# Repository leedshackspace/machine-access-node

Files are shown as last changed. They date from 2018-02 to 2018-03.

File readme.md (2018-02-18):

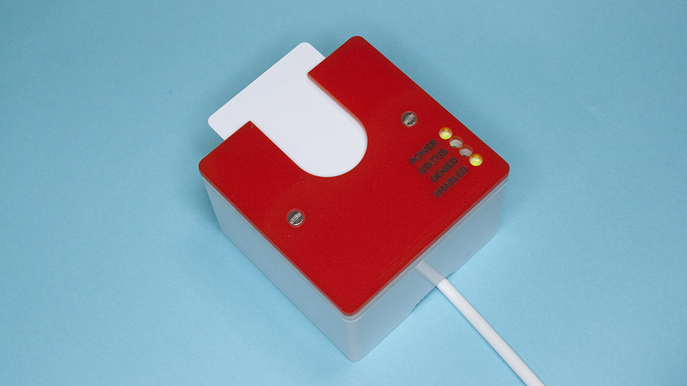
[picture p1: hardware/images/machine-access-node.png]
Machine Access Node


# Machine Node (WiFi)

Hardware and firmware to provide restricted access to dangerous and delicate
tools. Built around an ESP8266 (WeMos D1 mini) and RFID-RC522 breakout.

Designed to be easy to build for all levels of experience - simply order the PCB
from DirtyPCBs or OSHPark and solder the through hole parts to the board.
Software builds through the Arduino environment and will flash directly to the
WeMos board over USB.

## Hardware

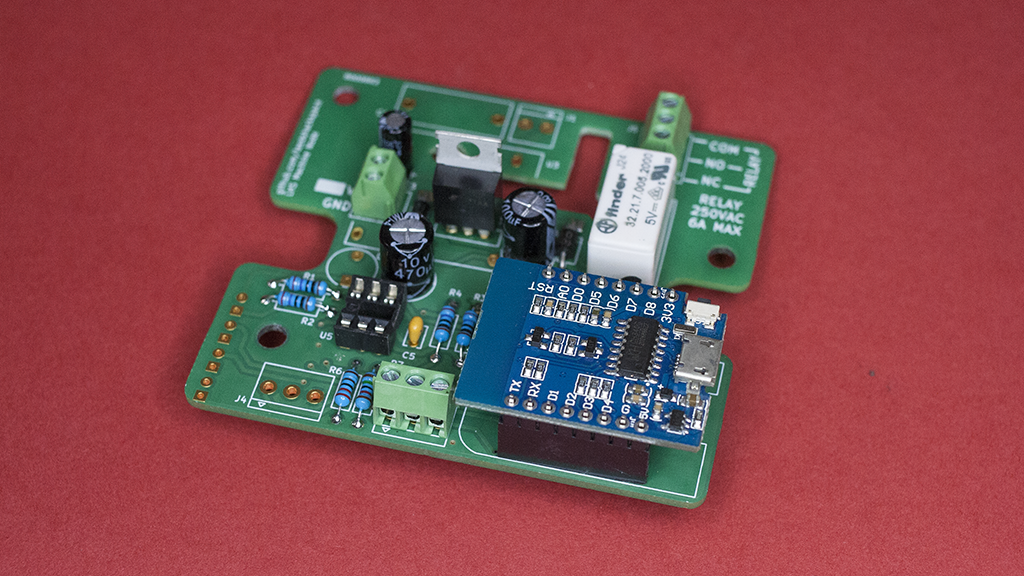
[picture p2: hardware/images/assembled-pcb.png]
Populated PCB


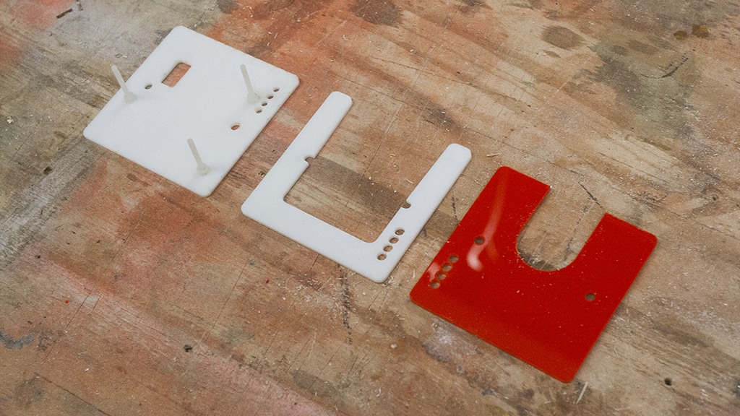
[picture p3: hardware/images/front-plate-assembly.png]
Faceplates for assembly


To build a machine node you simply need to acquire a PCB - gerbers are available
in the hardware folder - and order the parts listed in the BOM.

[Schematic](hardware/images/schematic-rev1.png).

### Power Supply Options

There are three power supply options.

* **12 V DC Power**  
  This is the recommended option. Populate the 12 V DC section of the schematic, and also `C4` if you wish.
* **5 V DC Power** (Untested)  
  Populate the 12 V DC section of the schematic, and do not fit `U2` or `D2`. Use a jumper wire to bridge `D2` and connect the solder jumper `JP1`.  
  There is no polarity protection in this configuration.
* **240 AC Mains Power** (Untested)  
  Populate the 240 V AC section of the schematic. There is a PTC fuse inside the AC-DC power supply `U3` but there should be external fusing as well to protect small gauge cabling coming into the terminals.

### Relay Contacts

The relay is rated for 250 V, 6 A max. If you are switching heavy loads it is recommended that you use this to trip an external contactor.

### Latch Mode

The default state is "Present" mode, that is, the output will turn on when the card
is present and it will turn off when it is removed. An as yet untested mode allows the
node to read a card once and then keep the output enabled until an external signal is
received.

Feel free to test this mode out, you can modify settings in `settings.h`. Remember to include a button to allow the user to cancel their session.

### Faceplate

Enclosure parts are for laser cutting and will fit a [deep surface mount
pattress box](https://www.screwfix.com/p/lap-1-gang-surface-pattress-box-w-cable-clamp-earth-terminal-white-46mm/28489) available from LAP. You need to countersink the "solid" back plate
and fit screws through into the backbox compartment to secure the PCB in place.
Nylon screws & nuts are recommended to secure the PCB to minimize any interference
with the RFID signal. Typical metal faceplate screws are acceptable to attach
the faceplate to the backbox.

## Software

### Library Requirements
* [MFRC522 RFID](https://github.com/miguelbalboa/rfid)
* [ArduinoJson](https://arduinojson.org/)
* [ESP8266RestClient](https://github.com/fabianofranca/ESP8266RestClient)

Modify `settings-example.h` and rename as `settings.h`.

Requires the [Tool API server](https://github.com/leedshackspace/tool-api) running somewhere accessible, at least until the cards have been cached.

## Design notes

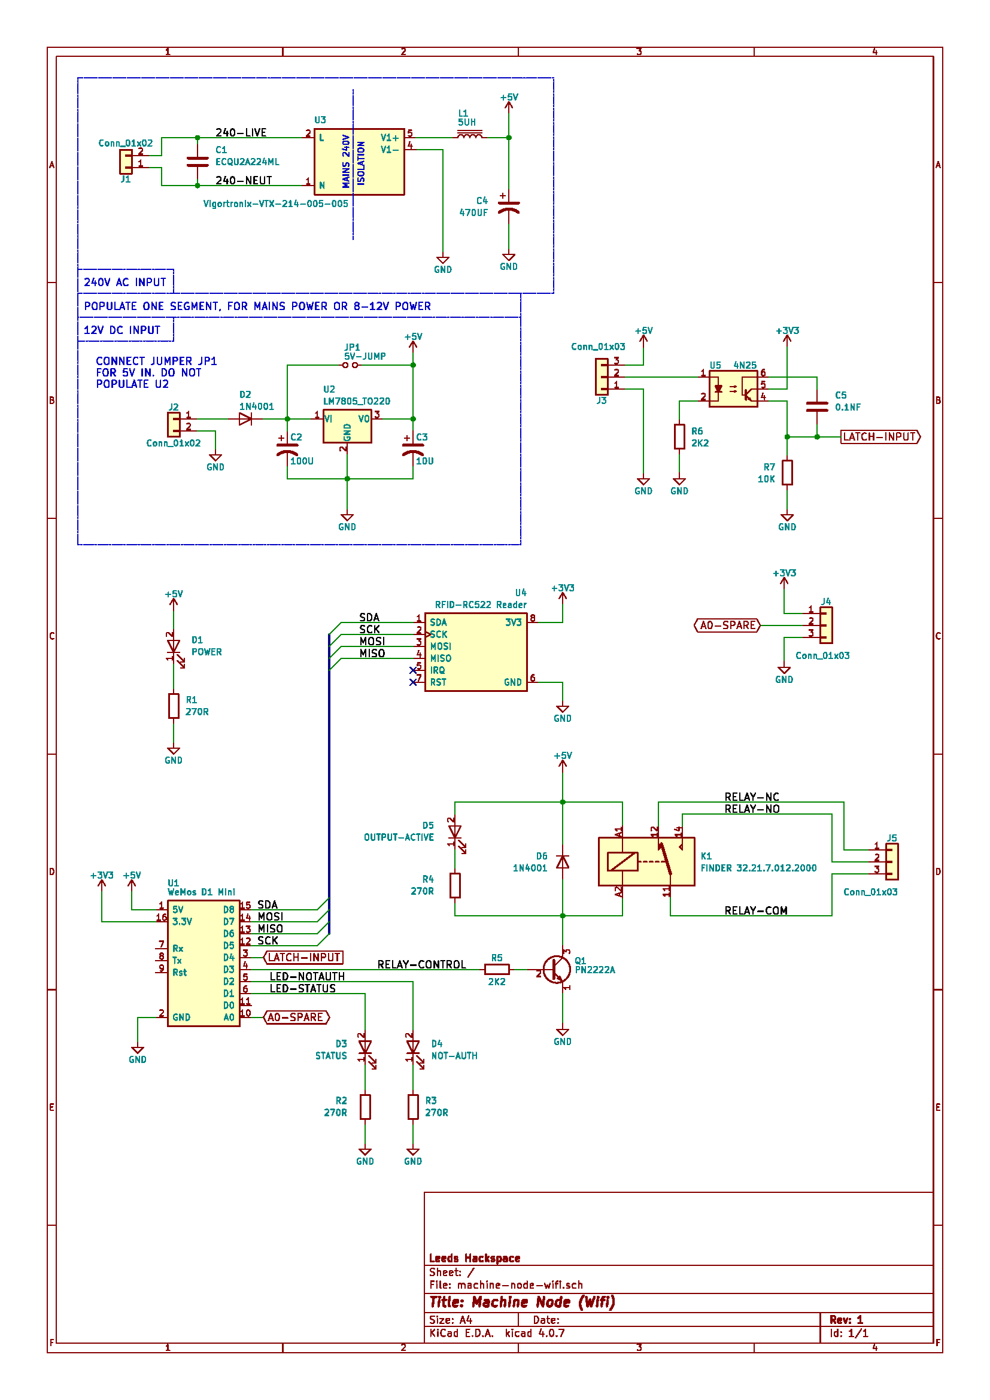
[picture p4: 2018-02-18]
hardware/images/schematic-rev1.png

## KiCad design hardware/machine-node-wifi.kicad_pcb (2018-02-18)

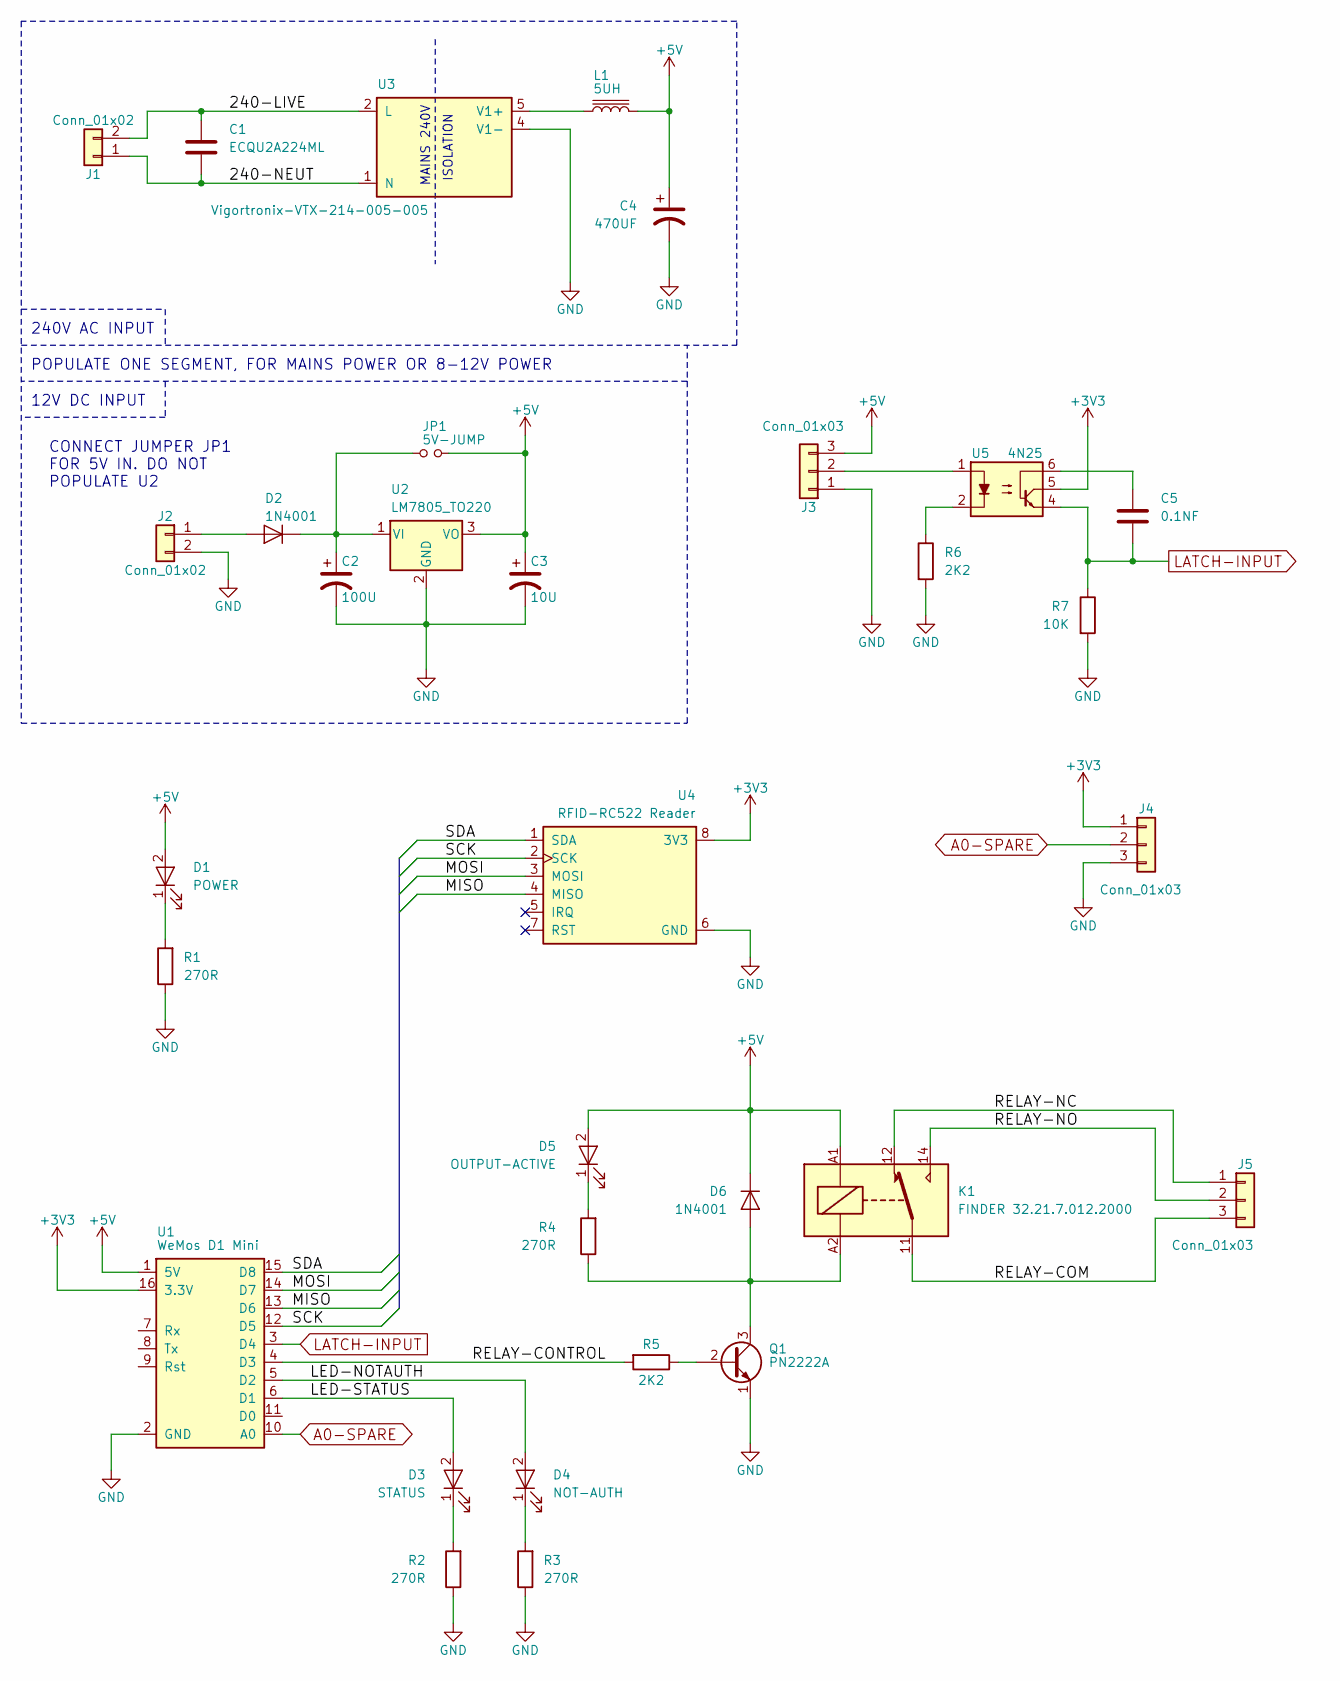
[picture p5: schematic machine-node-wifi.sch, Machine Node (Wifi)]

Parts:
C1: ECQU2A224ML; C_Rect_L18.0mm_W8.0mm_P15.00mm_FKS3_FKP3
C2: 100U; CP_Radial_D8.0mm_P3.50mm
C3: 10U; CP_Radial_D5.0mm_P2.00mm
C4: 470UF; CP_Radial_D8.0mm_P3.50mm
C5: 0.1NF; C_Rect_L4.0mm_W2.5mm_P2.50mm
D1: POWER; LED_D3.0mm
D2, D6: 1N4001; D_DO-41_SOD81_P10.16mm_Horizontal
D3: STATUS; LED_D3.0mm
D4: NOT-AUTH; LED_D3.0mm
D5: OUTPUT-ACTIVE; LED_D3.0mm
J1, J2: Conn_01x02; CONNECTOR-02-3.5MM
J3, J4, J5: Conn_01x03; CONNECTOR-03-3.5MM
JP1: 5V-JUMP; SOLDER-JUMPER_1-WAY
K1: FINDER 32.21.7.012.2000; Relay_SPDT_Finder_32.21-x000
L1: 5UH; INDUCTOR_V
Q1: PN2222A; TO-92_Molded_Narrow
R1, R2, R3, R4: 270R; R_Axial_DIN0207_L6.3mm_D2.5mm_P10.16mm_Horizontal
R5, R6: 2K2; R_Axial_DIN0207_L6.3mm_D2.5mm_P10.16mm_Horizontal
R7: 10K; R_Axial_DIN0207_L6.3mm_D2.5mm_P10.16mm_Horizontal
U1: WeMos D1 Mini; D1_mini_board
U2: LM7805_TO220; TO-220-3_Vertical
U3: Vigortronix-VTX-214-005-005; VTX-214-005-005
U4: RFID-RC522 Reader; Socket_Strip_Angled_1x08_Pitch2.54mm
U5: 4N25; DIP-6_W7.62mm

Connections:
+3V3: J4.1, U1.16 (3.3V), U4.8 (3V3), U5.5
+5V: C3.1, C4.1, D1.2 (A), D5.2 (A), D6.1 (K), J3.3, JP1.2, K1.A1, L1.1, U1.1 (5V), U2.3 (VO)
/240-LIVE: C1.1, J1.2, U3.2 (L)
/240-NEUT: C1.2, J1.1, U3.1 (N)
/LED-NOTAUTH: D4.2 (A), U1.5 (D2)
/LED-STATUS: D3.2 (A), U1.6 (D1)
/MISO: U1.13 (D6), U4.4 (MISO)
/MOSI: U1.14 (D7), U4.3 (MOSI)
/RELAY-COM: J5.3, K1.11
/RELAY-CONTROL: R5.2, U1.4 (D3)
/RELAY-NC: J5.1, K1.12
/RELAY-NO: J5.2, K1.14
/SCK: U1.12 (D5), U4.2 (SCK)
/SDA: U1.15 (D8), U4.1 (SDA)
A0-SPARE: J4.2, U1.10 (A0)
GND: C2.2, C3.2, C4.2, J2.2, J3.1, J4.3, Q1.1 (E), R1.1, R2.1, R3.1, R6.2, R7.2, U1.2 (GND), U2.2 (GND), U3.4 (V1-), U4.6 (GND)
LATCH-INPUT: C5.2, R7.1, U1.3 (D4), U5.4
unnamed: C2.1, D2.1 (K), JP1.1, U2.1 (VI)
unnamed: C5.1, U5.6
unnamed: D1.1 (K), R1.2
unnamed: D2.2 (A), J2.1
unnamed: D3.1 (K), R2.2
unnamed: D4.1 (K), R3.2
unnamed: D5.1 (K), R4.2
unnamed: D6.2 (A), K1.A2, Q1.3 (C), R4.1
unnamed: J3.2, U5.1
unnamed: L1.2, U3.5 (V1+)
unnamed: Q1.2 (B), R5.1
unnamed: R6.1, U5.2

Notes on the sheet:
POPULATE ONE SEGMENT, FOR MAINS POWER OR 8-12V POWER
240V AC INPUT
12V DC INPUT
MAINS 240V
ISOLATION
CONNECT JUMPER JP1 FOR 5V IN. DO NOT POPULATE U2

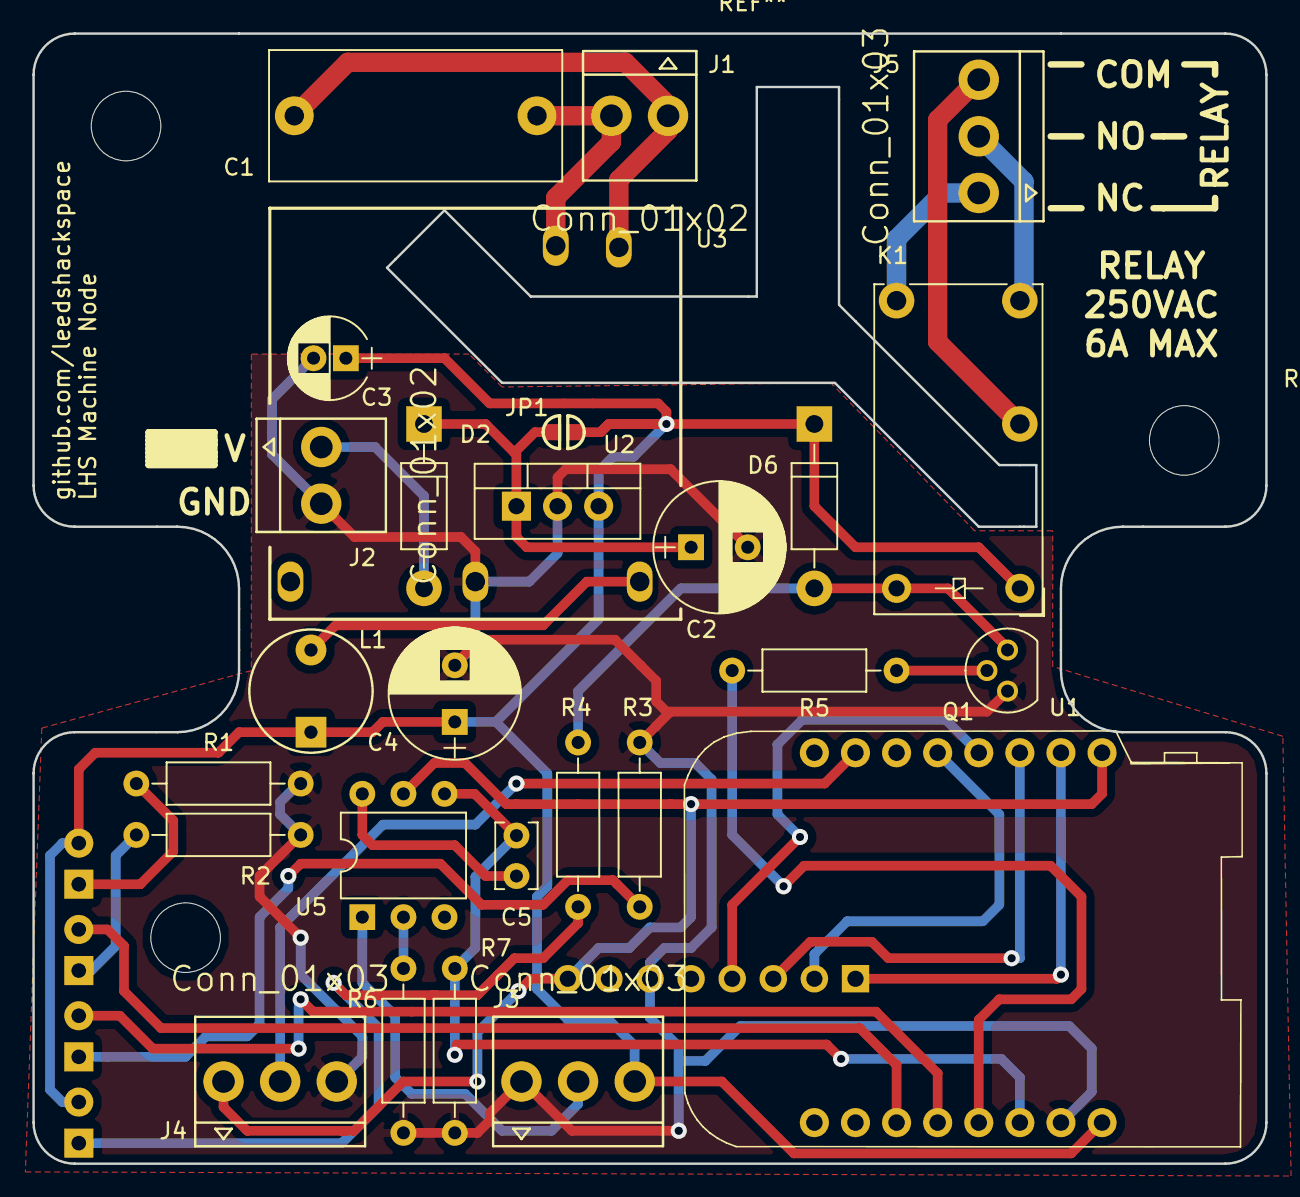
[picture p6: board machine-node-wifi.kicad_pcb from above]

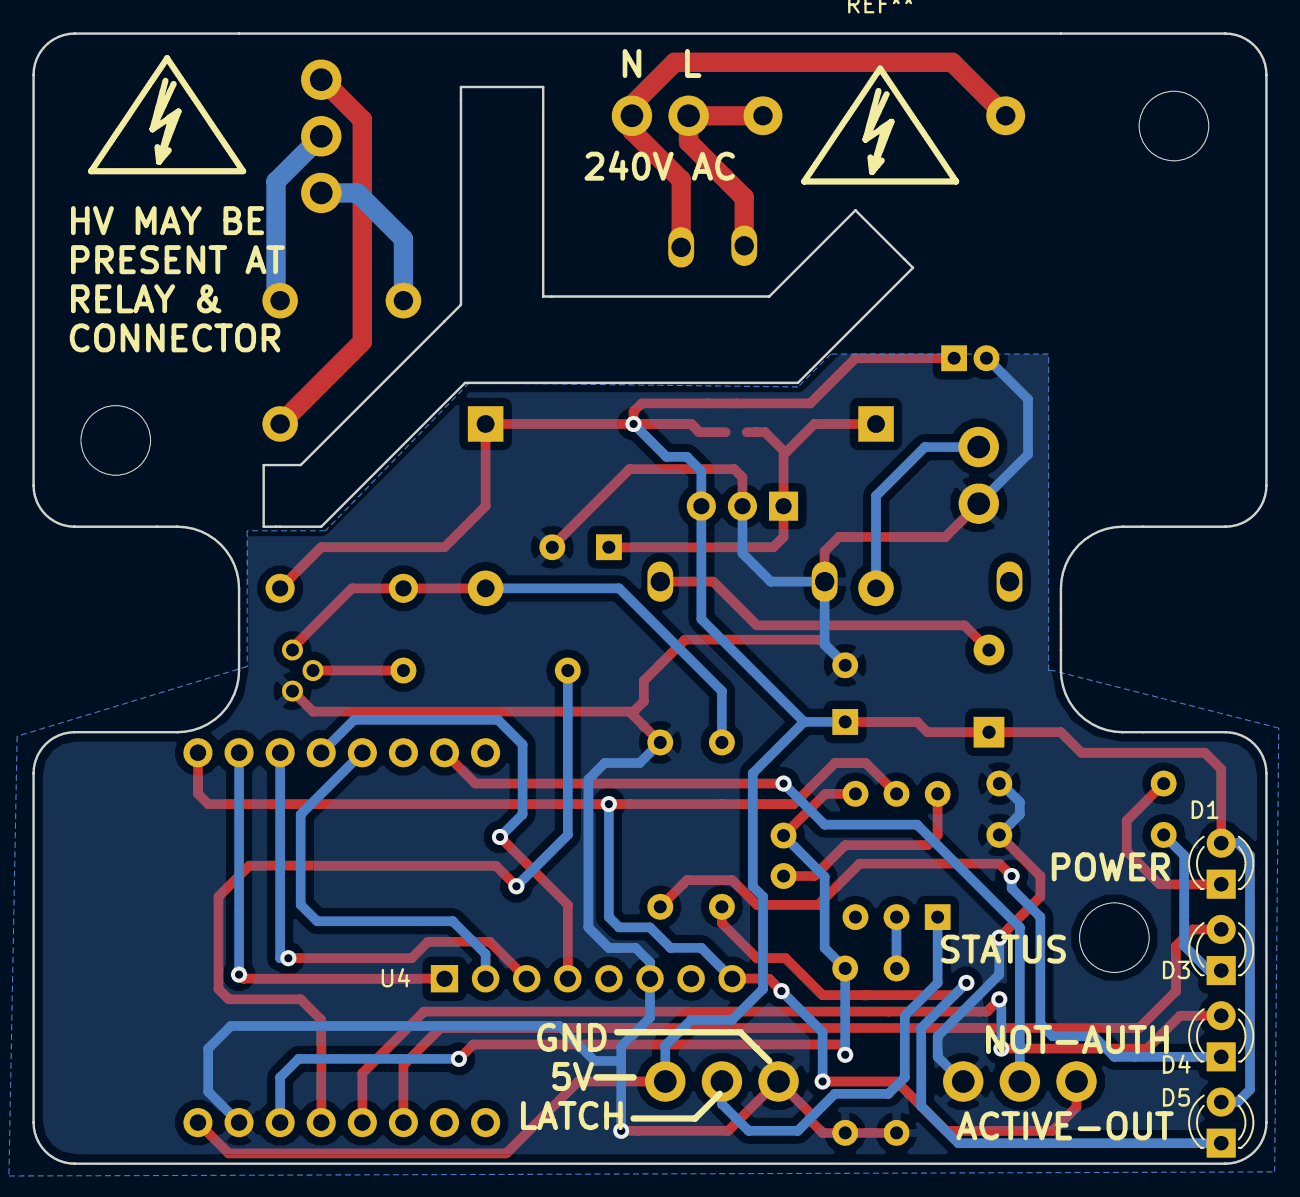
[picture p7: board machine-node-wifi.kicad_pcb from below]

Board: 2 copper layers, 76.2 x 69.9 mm, 32 parts (5 on the bottom side), 29 nets.

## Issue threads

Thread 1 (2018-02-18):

Relay latches at startup

adnbr, 2018-02-18:
The output relay switches itself at startup - this is related to the way that `Pin D3` on the WeMos is mapped as a special pin on the ESP8266 which determines where it should boot from. There's a brief moment when it's pulled high, and a pull down can't be used because it will interrupt boot.

The solution is to swap the status LED with the relay, as status is occupying a normal pin. Fix permanently with Revision 2.

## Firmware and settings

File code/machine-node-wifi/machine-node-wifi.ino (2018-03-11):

/*  Machine Node Wifi
 *  Check if a card is permitted to use a machine.
 *
 */
#define DEBUG
#define HTTP_DEBUG

#define AUTH_MODE_PRESENT 0
#define AUTH_MODE_LATCH   1


#include <ESP8266WiFi.h>
#include <MFRC522.h>
#include <RestClient.h>
#include <SPI.h>
#include <ArduinoJson.h>

#include "cardcache.h"
#include "settings.h"

struct rfidCard {
        String uid;
        bool canUse, canInduct;
        unsigned long firstSeen;
};


#define SPI_RFID_SS         D8
#define LED_OK              D1
#define LED_NOTAUTH         D2
#define RELAY               D3
#define LATCH_INPUT         D4

#define CARD_READ_RETRIES   8
#define READ_DELAY          100       // ms
#define WAIT_PERIOD         100       // ms

#define CARD_CLEAR_CACHE_1  "64ACC99A"
#define CARD_CLEAR_CACHE_2  "0498C19A"

RestClient client = RestClient(_PERMSURI_.c_str(), _PERMSPORT_);
MFRC522 rfid(SPI_RFID_SS);

CardCache cache("/perms.txt");
rfidCard currentCard = {"", false, false, 0};

int p = 0; // for aesthetic printing of "card still present" dots.


/*! Read the UID of the card presented to the RFID reader, returns a String.
 */

String readCardUID() {
        String uid = "";

        for (byte i = 0; i < rfid.uid.size; i++)
        {
                char buf [2];
                sprintf(buf,"%02X", rfid.uid.uidByte[i]);
                uid = uid + String(buf);
        }

        return uid;
}

/*! \brief Wait for a card to be presented to the RFID reader.
 *
 *  The RFID reader often "forgets" that it has a card present, and returns
 *  and incorrect result so this function will check multiple times for card
 *  presense before it gives up.
 *  This has the effect of a slight lag while running through the loop, but it
 *  doesn't get in the way of program execution.
 *  Returns false when no longer waiting for a card, returns true when no card present.
 */

bool waitingForCard() {
        int failedReads = 0;
        while(1)
        {
                if (failedReads > CARD_READ_RETRIES) {
                        return true;
                }
                // Is there a new card?
                if (!rfid.PICC_IsNewCardPresent())
                {
                        delay(READ_DELAY);
                        failedReads++;
                        continue;
                }
                // Can we read the serial?
                if (!rfid.PICC_ReadCardSerial())
                {
                        delay(WAIT_PERIOD);
                        failedReads++;
                        continue;
                }
                // Not waiting anymore.
                return false;
        }
}

/*! \brief GET the card permissions from the server
 *
 *  Assembles a GET request and sends it to the server. Returns a string which should contain JSON.
 */
String requestCardPermissionsJson (String carduid) {
        String response;

        // Make sure we aren't sent any HTML...
        client.setContentType("application/json");

        // Build the required string
        String requesturi = "/canuse/" + _MACHINEUID_ +"/" + carduid;
        Serial.println("GET " + _PERMSURI_ + requesturi);

        // Actually do the GET
        client.get(requesturi.c_str(), &response);
        Serial.println("Returned: " + response);
        return response;
}

/*! \brief Processes an incoming JSON string from the server and determines permissions.
 *
 *  Takes a JSON object array and a pointer to an rfidCard struct which will be modified
 *  during the processing. Returns true if the processing was a success, and false if there
 *  was a problem.
 *  The struct referenced by the pointer is _only_ modified if the JSON processing was successful.
 *  Expects:
 *  [{"canuse":1|0, "caninduct":1|0}]
 */

bool processPermissionsJson (String json, rfidCard* card) {

        const size_t bufferSize = JSON_ARRAY_SIZE(1) + JSON_OBJECT_SIZE(2) + 30;
        DynamicJsonBuffer jsonBuffer(bufferSize);

        JsonArray& root = jsonBuffer.parseArray(json);
        if (!root.success())
        {
                Serial.println(F("Error, could not parse returned JSON."));
                return false;
        } else
        {
                card->canUse = root[0]["canuse"];
                card->canInduct = root[0]["caninduct"];
                Serial.println(F("Parsed JSON OK."));
                Serial.println("CanUse: " + String(card->canUse) + ", CanInduct: " + String(card->canInduct));
                return true;
        }
}


/*! Performs the actions required to either enable or disable
 *  the output, along with the associated UI changes.
 */
void setOutputState (bool permitted) {
        if (permitted == true)
        {
                digitalWrite(RELAY, true);
                digitalWrite(LED_NOTAUTH, false);
        } else
        {
                digitalWrite(RELAY, false);
                digitalWrite(LED_NOTAUTH, true);
        }
}


void checkCard (rfidCard* card) {
        rfidCard checkingCard = *card;
        // Try a few times to get the information from the server
        // if there is no response and the card UID doesn't exist
        // in the
        for (int i = 1; i <= 3; i++)
        {       
                String cardInfo = "";
                
                // If the WiFi is connected then try to get the data from the
                // server.
                if (WiFi.status() == WL_CONNECTED)
                {
                    // GET the JSON from the server
                    cardInfo = requestCardPermissionsJson(checkingCard.uid);
                } else 
                {
                    Serial.println(F("Wifi not connected. Not checking server."));
                }
                
                // Attempt to process the data, load it into the currentCard struct.
                // Failure to GET from the server or
                if (processPermissionsJson(cardInfo, &checkingCard))
                {
                        if (checkingCard.canInduct) {
                                // Potential to break out here.
                                // Induct a user.
                        }
                        // Does currentCard.canUse = 1? Add it to the cache :else: delete the card
                        checkingCard.canUse ? cache.addUid(checkingCard.uid) : cache.delUid(checkingCard.uid);
                        break;

                } else
                {
                        checkingCard.canInduct = false;
                        // We can't make any sense of the response we've
                        // got from the server, so let's give the local cache a poke
                        if (cache.doesUidExist(checkingCard.uid))
                        {
                                // Non-zero response means the uid exists.
                                checkingCard.canUse = true;
                                Serial.println(F("Card found in cache. Output enabled."));
                                break;
                        } else
                        {
                                checkingCard.canUse = false;
                                Serial.println(F("Card not found in cache. Output disabled."));
                                break;
                        }
                }
        } // for
        *card = checkingCard;
}



/*  Push the usage time log to the server as a JSON string.
 *  Returns TRUE if the server replies 200, returns FALSE otherwise.
 */

bool sendLog (unsigned long elapsed, String cardUid) {
        String body, response;

        // Create the JSON string we will be sending to the server.
        const size_t bufferSize = JSON_OBJECT_SIZE(3);
        DynamicJsonBuffer jsonBuffer(bufferSize);

        JsonObject& root = jsonBuffer.createObject();

        root["machineuid"] = _MACHINEUID_;
        root["carduid"] = cardUid;
        root["elapsed"] = elapsed;

        root.printTo(body);

        // Tell server we're sending JSON.
        client.setContentType("application/json");

        // Build the request string
        String requesturi = "/log/new";
        Serial.println("POST " + _PERMSURI_ + requesturi);
        Serial.println(body);
        //body =  "machineuid=" + _MACHINEUID_ + "&carduid=" + cardUid + "&elapsed=" + elapsed;
        // Actually do the POST, grab the returned status code.
        //int status = client.post(requesturi.c_str(), body.c_str(), &response);
        int status = client.post(requesturi.c_str(), body.c_str(), &response);
        Serial.println(String(status) + " Returned: " + response);

        // If successful (HTTP 200) return true.
        if (status == 200)
        {
                return true;
        } else
        {
                return false;
        }

}


unsigned long calculateElapsedSeconds (unsigned long startTime) {
        unsigned long elapsedTimeSeconds =  (millis() - startTime) / 1000;
        Serial.println("\r\nTime Output Enabled: " + String(elapsedTimeSeconds) + " s");
        return elapsedTimeSeconds;
}


/*  Wipe all the details of the referenced rfidCard, ready
 *  for the next card to come along.
 */
void wipeCard (rfidCard* card) {
        card->canUse = false;
        card->canInduct = false;
        card->uid = "";
        card->firstSeen = 0;
}


void setup() {
        // Above all else, make sure that we turn off the output relay first.
        pinMode(RELAY, OUTPUT);
        digitalWrite(RELAY, LOW);

        // Now we can do the normal setup stuff. Start the Serial, SPI and init the rfid
        // Also increase the antenna gain for the RFID for more reliable reading at distance
        Serial.begin(115200);
        SPI.begin();
        rfid.PCD_Init();
        rfid.PCD_SetAntennaGain(112);

        cache.setup();

        // The latch input will go high or low once the process has finished.
        // This allows the user to remove their card on long, unattended jobs
        // such as 3D printing or the power hacksaw.
        pinMode(LATCH_INPUT, INPUT);

        pinMode(LED_OK, OUTPUT);
        pinMode(LED_NOTAUTH, OUTPUT);
        digitalWrite(LED_OK, LOW);
        digitalWrite(LED_NOTAUTH, LOW);

        Serial.println(F("Machine Node"));
        Serial.println("Machine UID: " + _MACHINEUID_);

        Serial.print(F("Connecting to wireless network: "));
        Serial.print(ssid);
        WiFi.begin(ssid.c_str(), pass.c_str());
        int i = 0;
        while (WiFi.status() != WL_CONNECTED && i < 20)
        {
                i++;
                delay(500);
                Serial.print(".");
        }

        // Wifi connected.
        if (WiFi.status() != WL_CONNECTED)
        {
            Serial.println("Wifi connection failure.");
        } else {
            Serial.println("Wifi connected.");
            digitalWrite(LED_OK, HIGH);
        }
        setOutputState(false);
}

void loop() {
        if (!waitingForCard())
        {
                // Card here, grab the UID from it.
                String presentedCard = readCardUID();
                // If this is a new card then check its credentials.
                // Otherwise it's probably fine.
                if (presentedCard == CARD_CLEAR_CACHE_1 || presentedCard == CARD_CLEAR_CACHE_2)
                {
                        // One of the hard-coded "Special" cards has been presented.
                        // These are used to force the cache to be deleted.
                        setOutputState(false);
                        digitalWrite (LED_OK, LOW);
                        digitalWrite (LED_NOTAUTH, LOW);
                        cache.setup(true); // Format
                        delay(1000);
                        digitalWrite(LED_OK, HIGH);
                        digitalWrite (LED_NOTAUTH, HIGH);
                }
                if (currentCard.uid!= presentedCard)
                {
                        currentCard.uid = presentedCard;
                        Serial.print(F("\r\nRead Card: "));
                        Serial.println(presentedCard);
                        checkCard(&currentCard);
                        currentCard.firstSeen = millis();
                        p = 0;
                } else {
                        if (p > 40)
                        {
                                // If card is not allowed (canUse == false) print exclamation mark
                                // to indicate that this time isn't being tracked.
                                currentCard.canUse ? Serial.print(". ") : Serial.print(". !");
                                Serial.println( String((millis() - currentCard.firstSeen) / 1000));
                                p = 0;
                        } else
                        {
                                Serial.print(".");
                                p++;
                        }
                }
        } else if (!rfid.PICC_IsNewCardPresent())
        {
                // Card has gone away.
                switch (_AUTHMODE_) {
                case AUTH_MODE_PRESENT:
                        if (currentCard.canUse && currentCard.uid != "")
                        {
                                setOutputState(false);
                                // Calculate seconds elapsed from milliseconds, send it to the server for logging.
                                sendLog(calculateElapsedSeconds(currentCard.firstSeen), currentCard.uid);
                                wipeCard(&currentCard);
                        }
                        break;
                case AUTH_MODE_LATCH:
                        if (digitalRead(LATCH_INPUT) == _LATCHDISABLESTATE_)
                        {
                                sendLog(calculateElapsedSeconds(currentCard.firstSeen), currentCard.uid);
                                wipeCard(&currentCard);
                        }
                        break;
                }
        }
        // Update the current output state for the card presented.
        setOutputState(currentCard.canUse);

        // Update the Wifi Status LED. Lit is OK.
        WiFi.status() == WL_CONNECTED ? digitalWrite(LED_OK, HIGH) : digitalWrite(LED_OK, LOW);

}

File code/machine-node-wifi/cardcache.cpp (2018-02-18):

#include "Arduino.h"
#include "FS.h"
#include "cardcache.h"

#define BLANK_UID "        "


#define DEBUG

#ifdef DEBUG

#define DEBUG_PRINT(x)  Serial.print (x)
#define DEBUG_PRINTLN(x) Serial.println (x)

#else

#define DEBUG_PRINT(x)
#define DEBUG_PRINTLN(x)

#endif


/*! Starts the SPI File System used for file storage and copies the filename to a private
 *  class variable for use later on. There is no default filename/path.
 */
CardCache::CardCache (String file) {
        _file = file;
        SPIFFS.begin();
}

/*! \brief Add a card UID to the local cache. 
 *
 *  First checks if the UID is present in the cache already. If the entry is present
 *  in the cache it will not be added again.
 * 
 *  Returns true if the UID was added, returns false if UID was not added because it already exists. 
 */
 
 bool CardCache::addUid (String uid) {
        if (!this->doesUidExist(uid)) {
                // Card not in the cache already, so add it.
                this->writeUid(uid);
                DEBUG_PRINT(F("addToCache: Added new: "));
                DEBUG_PRINTLN(uid);
                return true; // Added the card
        } else {
                DEBUG_PRINT(F("addToCache: Already exists: "));
                DEBUG_PRINTLN(uid);
                return false; // Didn't add the card, already existed.
        }
}


/*! \brief Prepare the cache for use by checking for the presence of the cache file, and
 *         creating the file if it isn't found. Includes the option to "format" the filesystem. 
 *
 *  First checks if the UID is present in the cache already. If the entry is present
 *  in the cache it will not be added again.
 * 
 *  Returns true if the UID was added, returns false if UID was not added because it already exists. 
 */

void CardCache::setup (bool format) {

        FSInfo fs_info;
        SPIFFS.info(fs_info);

        DEBUG_PRINTLN(F("File System Data:"));
        DEBUG_PRINT(F("Total Space:\t"));
        DEBUG_PRINTLN(fs_info.totalBytes);
        DEBUG_PRINT(F("Used Space:\t"));
        DEBUG_PRINTLN(fs_info.usedBytes);
        DEBUG_PRINT(F("Free Space:\t"));
        DEBUG_PRINTLN(fs_info.totalBytes - fs_info.usedBytes);
        DEBUG_PRINTLN("File: " + _file);

        // We've been asked to format the free space, this will force the rest of the function
        // to fail to "couldn't read the file." and clear the cache.
        if (format) {
                SPIFFS.format() ? DEBUG_PRINTLN("setup: Formatted OK.") : DEBUG_PRINTLN("setup: Free space format failed.");
        }
        // Open the file in read mode.
        File f = SPIFFS.open(_file, "r+");

        // If the opening fails it probaby doesn't exist, make the file.
        if (!f) {
                DEBUG_PRINTLN(F("Cache doesn't exist. Creating it."));

                File f = SPIFFS.open(_file, "w+");
                if (!f) {
                        DEBUG_PRINTLN(F("Couldn't create cache."));
                }
                // Write the title. We aren't storing a Card UID on the first "row"
                // which allows us to use 0 as false/not found when referring to a location.
                f.println("AUTH UID");

        } else {
                DEBUG_PRINTLN(F("Current authorised UIDs"));
                // We have opened the file, now print everything in it to the serial port.
                while (f.available()) {
                        // Read until the newline character.
                        String line = f.readStringUntil('\n');
                        DEBUG_PRINTLN(String(f.position() - 10) + "\t" + line);
                }

        }

        f.close();
}

/*! Clear the cache. Try to remove the file, then run the setup to establish a new cache
 *  if successful. Returns true if cache was removed, false if the cache couldn't be removed.
 */

bool CardCache::clearCache () {
        if (SPIFFS.remove(_file)) {
                DEBUG_PRINTLN(F("clearCache: Deleted cache."));
                this->setup();
                return true;
        } else {
                DEBUG_PRINTLN(F("clearCache: Could not delete."));
                return false;
        }
}

/*! \brief Remove a card UID from the local cache. 
 *
 *  Searches through the cache for all instances of the provided UID, and 
 *  continues searching until the doesUidExist call returns false.
 *  Returns the number of entries it deleted.
 *  In theory this extended search shouldn't be nessecary as if the UID already
 *  exists it cannot be added, but we're covering all the bases here in case there is
 *  a hiccup somewhere along the line.
 */
int CardCache::delUid (String uid) {
        unsigned long location = this->doesUidExist(uid);
        int i = 0;
        while (location) {
                DEBUG_PRINT(F("delUid: Deleting UID: "));
                DEBUG_PRINTLN(uid + " at position " + location);
                this->scrubPosition (location);
                location = this->doesUidExist(uid);
                i++;
        }
        DEBUG_PRINT(F("delUid: Num entries deleted: "));
        DEBUG_PRINTLN(i);
        return i;
}


/*! \brief Checks if a UID is present in the cache.
 *
 *  Searches through the cache for the first instance of the UID provided in the cache.
 *  This function will only return the first instance, and not anything after. Currently
 *  it is limited in counting 8-byte UIDs - storing longer UIDs may result in a problem.
 *  Returns the location of the start of the entry, or 0, which indicates not found.
 */
unsigned long CardCache::doesUidExist (String uid) {
        File f = SPIFFS.open(_file, "r");
        if (!f) {
                DEBUG_PRINTLN(F("Couldn't open permissions file."));
                return false; // 0
        } else {
                // we could open the file
                while (f.available()) {
                        //Lets read line by line from the file
                        String line = f.readStringUntil('\n');
                        String compare = uid + String("\r");
                        if (line == compare)
                        {
                                // Current hardcoding of card length.
                                // TODO: Detect previous EOL markers and run up to there, allow for
                                // non-uniform card length detection.
                                int location = f.position() - 10;
                                f.close();
                                return location;
                        }
                }
                f.close();
                return false; // 0
        }
}
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

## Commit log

2018-02-18 First commit - KiCad & Gerbers
    KiCad schematic and layout files, gerbers.
    [machine-node-wifi-B.Cu.gbr, machine-node-wifi-B.Mask.gbr, machine-node-wifi-B.SilkS.gbr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]
2018-02-18 First commit - Enclosure hardware
2018-02-19 No wifi, don't check server
    If the WiFi isn't connected then don't bother trying to talk to the
    server - speeds up the response and prevents spurious ESP exceptions.
    [machine-node-wifi.ino]
2018-03-11 Start log timer after card has been checked
